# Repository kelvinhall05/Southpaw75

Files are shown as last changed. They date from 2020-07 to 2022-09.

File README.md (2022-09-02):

# Southpaw75

The Southpaw75 is a budget FR4 keyboard designed to make a southpaw-style layout available to everyone with as few compromises as possible.

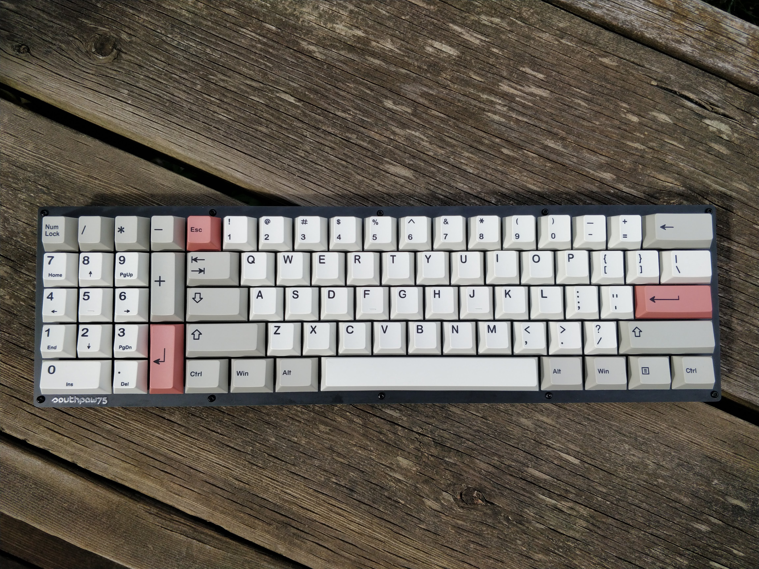
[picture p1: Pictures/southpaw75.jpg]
Image of Southpaw


### Disclaimer: You must follow this guide in the order it is written. Assembling stuff in the wrong order (specifically your Pro Micro or Elite C and its headers) will likely result in you having to desolder components and significantly increase the amount of time it takes to assemble. I am not responsible for boards damaged during assembly. I highly recommend you read through the entire guide before starting assembly.

### Please also note that the pictures in this guide were mostly taken after I had already assembled a prototype, and I did not have enough diodes or any switches to fully assemble another board. Please only use the pictures in this guide as a reference for the step they follow and not as the guide itself.

# Assembly:
### This is what the back of an empty PCB looks like (please note, the GB version has some minor changes):
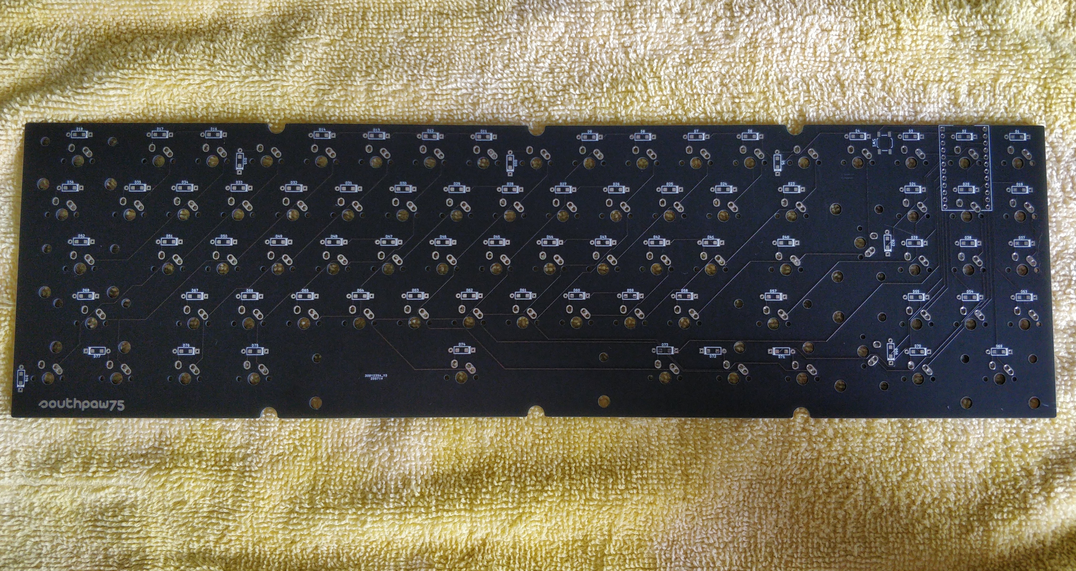
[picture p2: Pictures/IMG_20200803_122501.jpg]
Image of empty PCB

### 1. Bend the legs of all your diodes so they look like this:
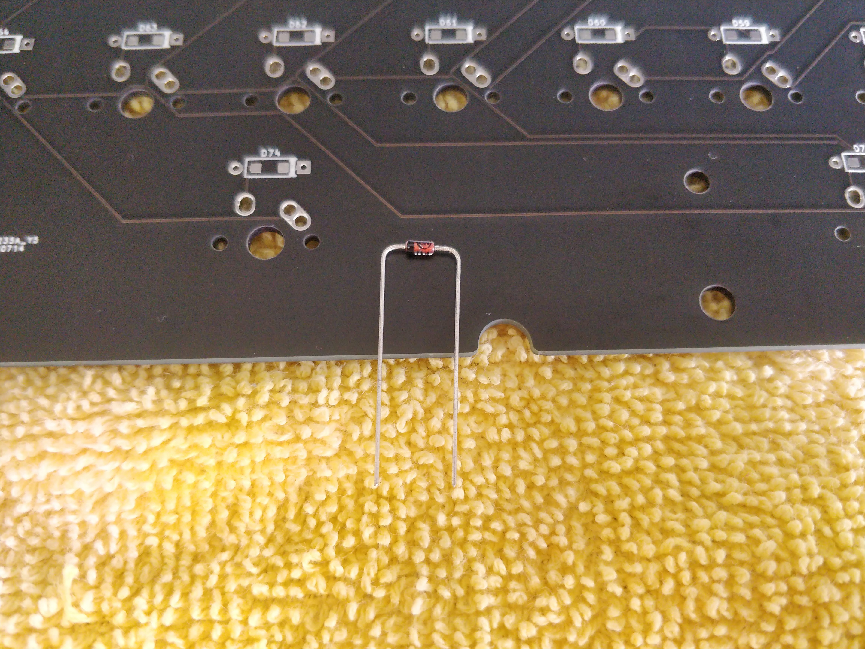
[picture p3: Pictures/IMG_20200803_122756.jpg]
Image of diode legs

### 2. Put the diodes through the PCB so the legs stick out the front side of the board and so the diode is flush with the back, making sure the black line on the diode faces the square pad:
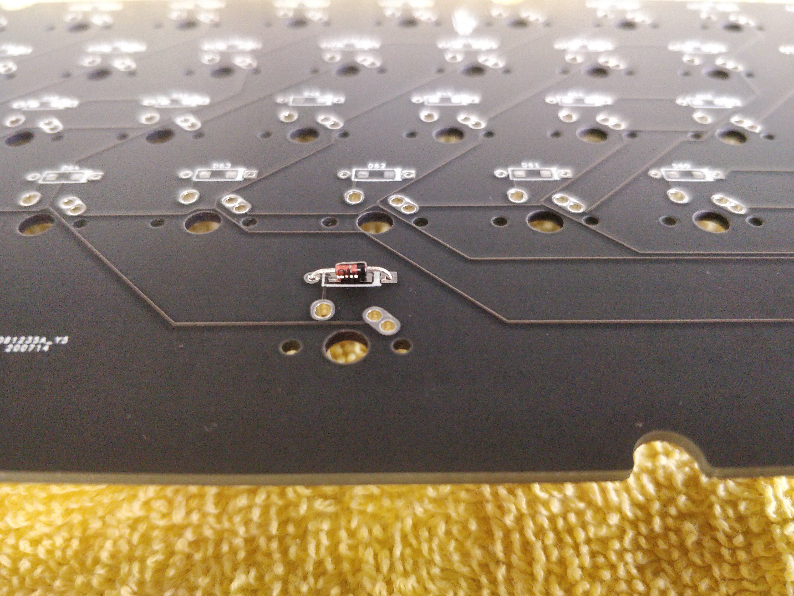
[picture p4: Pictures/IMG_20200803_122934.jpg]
Image of diode in PCB

### 3. Solder from the back and snip the legs:
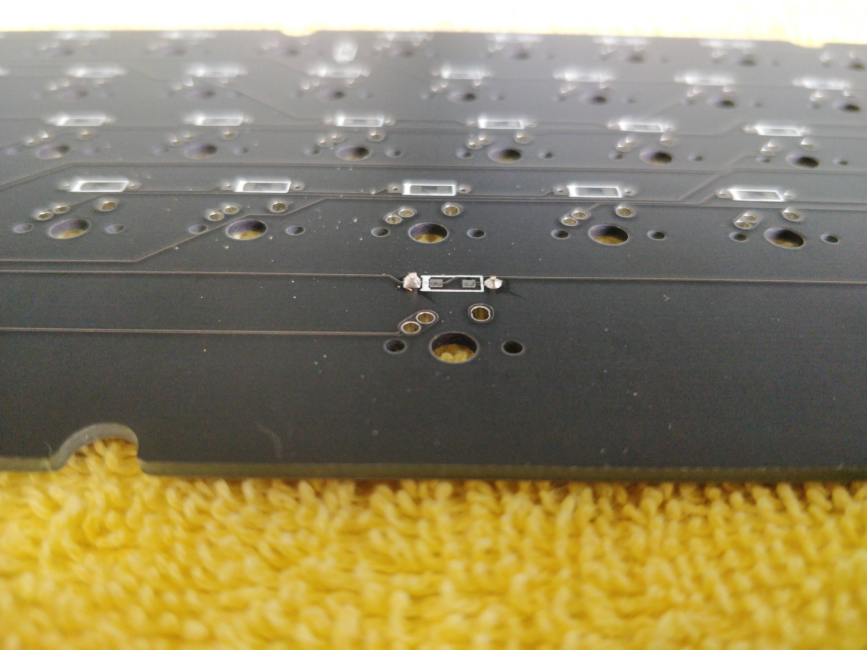
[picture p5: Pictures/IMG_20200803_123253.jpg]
Image of soldered diode

### 4. Repeat for all diodes (you will have to solder 78, and you may have several extras). Please note that several diodes have their footprint rotated but are electrically identical, meaning black stripe will still go to square pad.
### 5. Solder your reset button to the PCB (use tweezers to hold it down, as the metal will conduct heat from your iron and burn your finger)
### Note: If you've lost your reset button, don't worry. Shorting the two pads closest to the edge of the PCB or the two closest to the inside will reset your controller. After all, that's all the button does :)
### 6. Place your Pro Micro or Elite C onto its pin headers and sit it into the board so the Pro Micro is on the back of the PCB (the side with the Southpaw logo) and tape it down to temporarily hold it in place. This helps align the pin headers properly. It doesn't matter whether you put the shorter pins on the PCB or the longer ones; either way, you will have to snip the longer ones once you've soldered them in. **DO NOT SOLDER THE PRO MICRO OR ELITE C TO THE PIN HEADERS YET!**
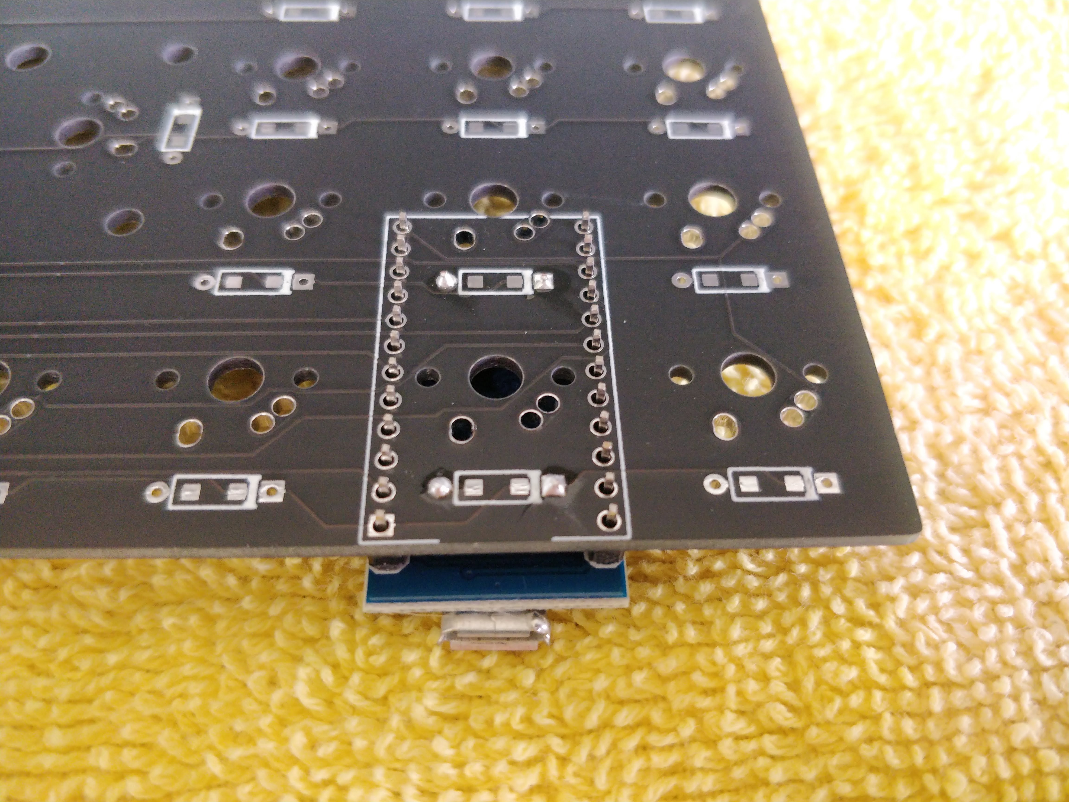
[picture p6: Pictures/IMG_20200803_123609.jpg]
Image of seated Pro Micro

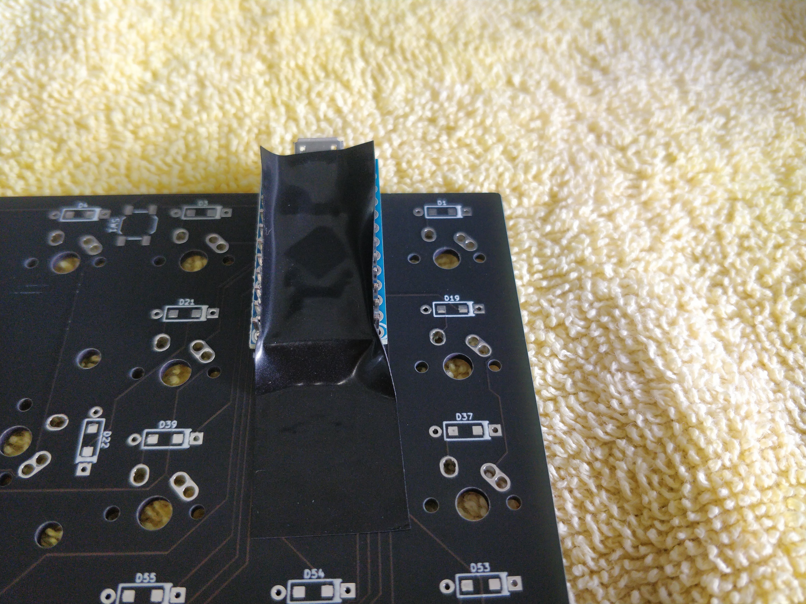
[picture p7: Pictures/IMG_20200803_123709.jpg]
Image of taped Pro Micro

### 7. Solder in the pin headers from the front side of the PCB. **Do not solder the Pro Micro or Elite C yet, just the headers!**
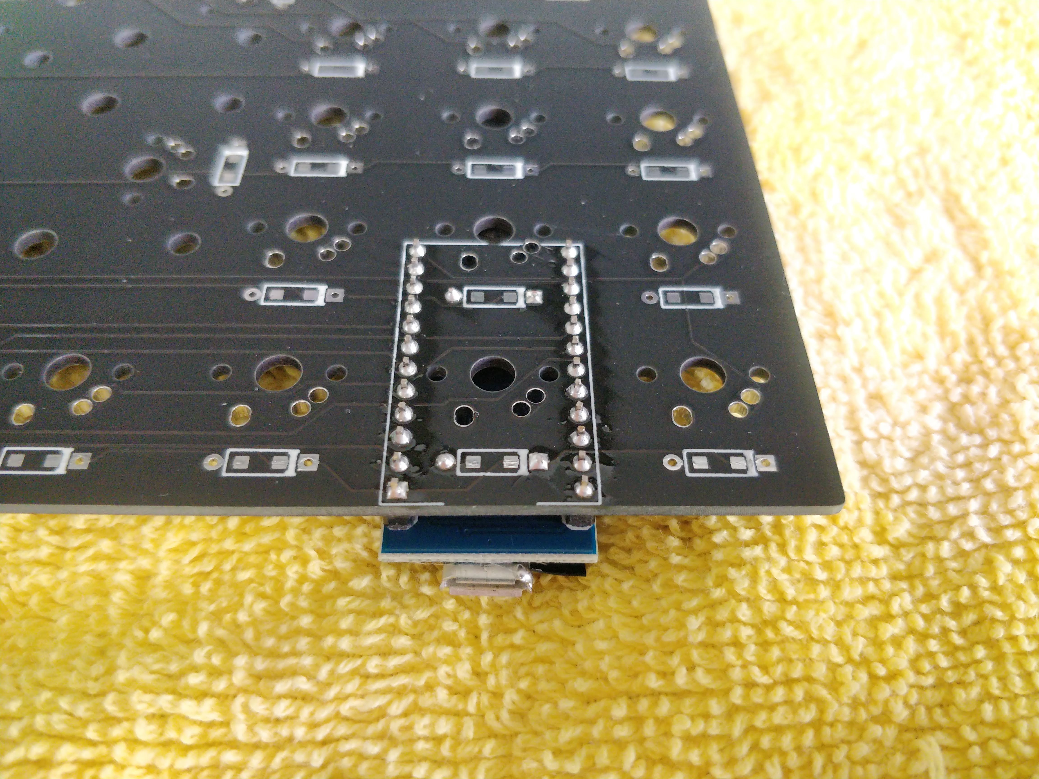
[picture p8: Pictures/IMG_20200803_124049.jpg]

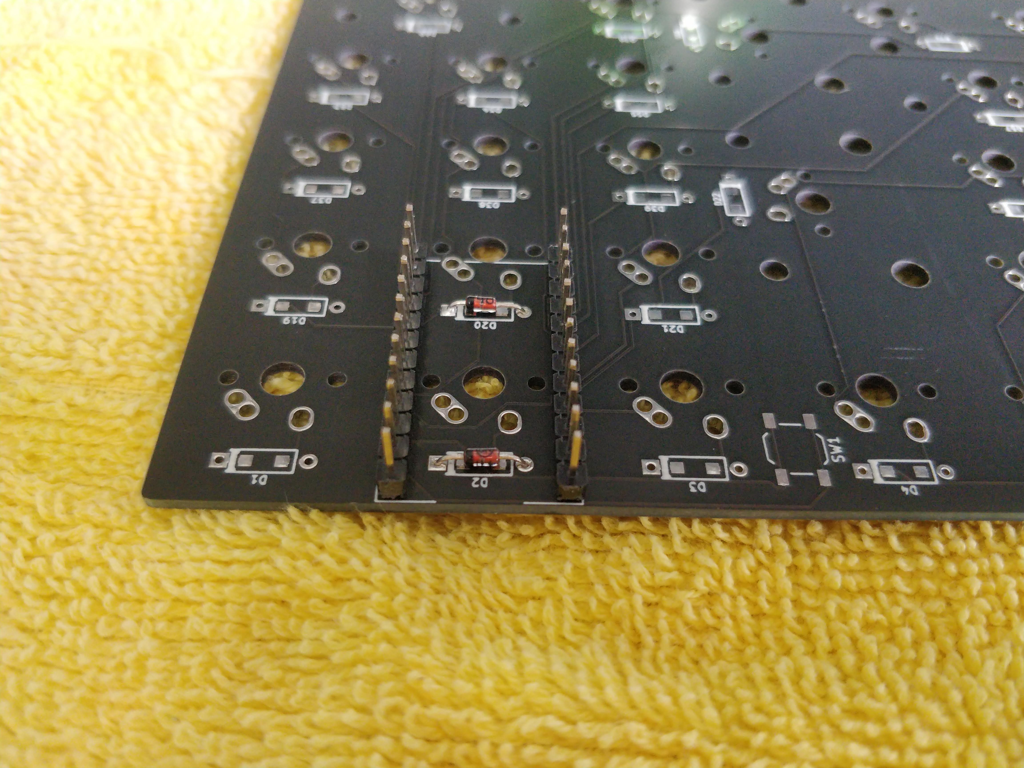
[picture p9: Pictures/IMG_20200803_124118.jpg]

### 8. Attach your stabs to the PCB (some PCB stabs might be a tight fit with the plate; do not be afraid to push, you won't break it)
### 9. Mount switches in the corner of the plate to align it, then lower the plate onto the PCB
### 10. Add the rest of your switches and solder them all in
### 11. Once you have verified that all your diodes, switches, and Pro Micro or Elite C pin headers are soldered properly, you can now solder your Pro Micro or Elite C onto the pin headers:
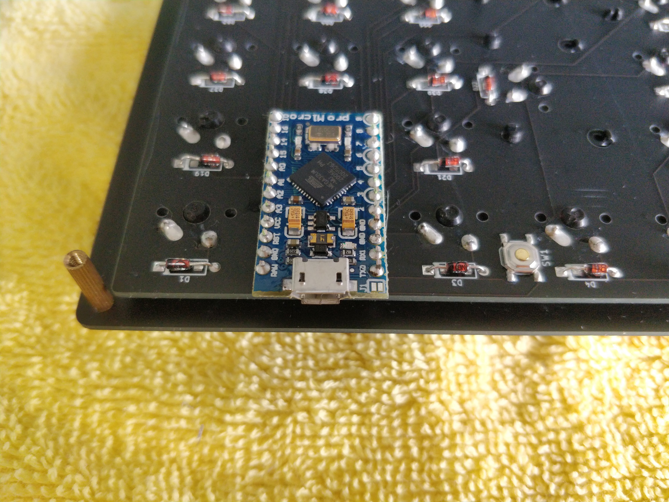
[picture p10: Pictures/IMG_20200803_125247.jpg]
Image of soldered Pro Micro

### Here is what a completed PCB will look like:
Image of completed PCB
### 12. Attach standoffs to the bottom of the plate using screws from the other side
### 13. Screw on the bottom plate
# Flashing instructions for Linux:
### 1. Plug your Pro Micro or Elite C in
### 2. Open up the [QMK configurator](https://config.qmk.fm/#/southpaw75/LAYOUT) and create your desired layout
### 3. Download the .json file (on the left, next to keymap.json)
### 4. Open up a command line
### 5. Type ```qmk flash /path/to/layout.json``` (obviously replacing the file path with the path to your downloaded layout) and follow any additional instructions
### One thing to note is that you can compile a .hex file on the configurator and flash that with avrdude, however, I prefer the method outlined above.
# Flashing instructions for Windows:
### Please keep in mind that I do not run Windows on my own system and cannot 100% verify this flashing procedure will work or if it requires any other configuration. I highly recommend you check the QMK docs if something is not working. I am unable to help with any flashing problems if you run Windows.
### 1. Plug your Pro Micro or Elite C in
### 2. Open up the [QMK configurator](https://config.qmk.fm/#/southpaw75/LAYOUT) and create your desired layout
### 3. Click "compile" in the upper right, and once it's done, download the .hex by clicking "firmware"
### 4. Open up QMK toolbox and load your downloaded .hex
### 5. Click "flash" and follow any additional instructions

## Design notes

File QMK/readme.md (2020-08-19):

# Southpaw75

Southpaw75

60% with southpaw numpad.

* Keyboard Maintainer: [kelvinhall05](https://github.com/kelvinhall05/)
* Hardware Supported: Southpaw75 Pro Micro PCB
* Hardware Availability: https://github.com/kelvinhall05/southpaw75

Make example for this keyboard (after setting up your build environment):

    make southpaw75:default

See the [build environment setup](https://docs.qmk.fm/#/getting_started_build_tools) and the [make instructions](https://docs.qmk.fm/#/getting_started_make_guide) for more information. Brand new to QMK? Start with our [Complete Newbs Guide](https://docs.qmk.fm/#/newbs).

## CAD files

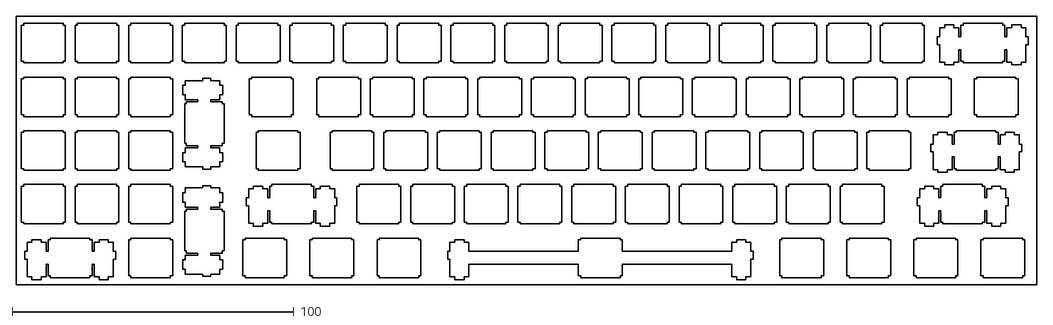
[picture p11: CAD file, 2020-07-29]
Plate/plate.dxf
361.9 x 95.2

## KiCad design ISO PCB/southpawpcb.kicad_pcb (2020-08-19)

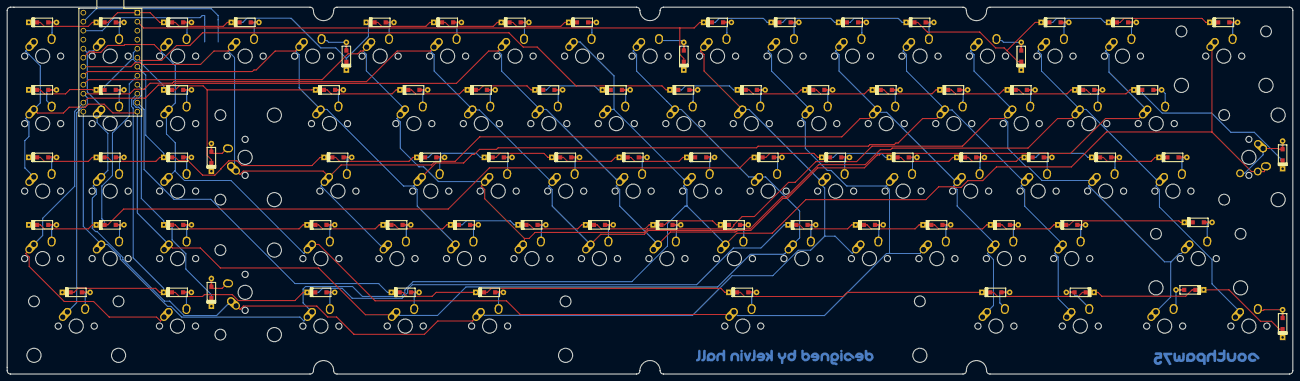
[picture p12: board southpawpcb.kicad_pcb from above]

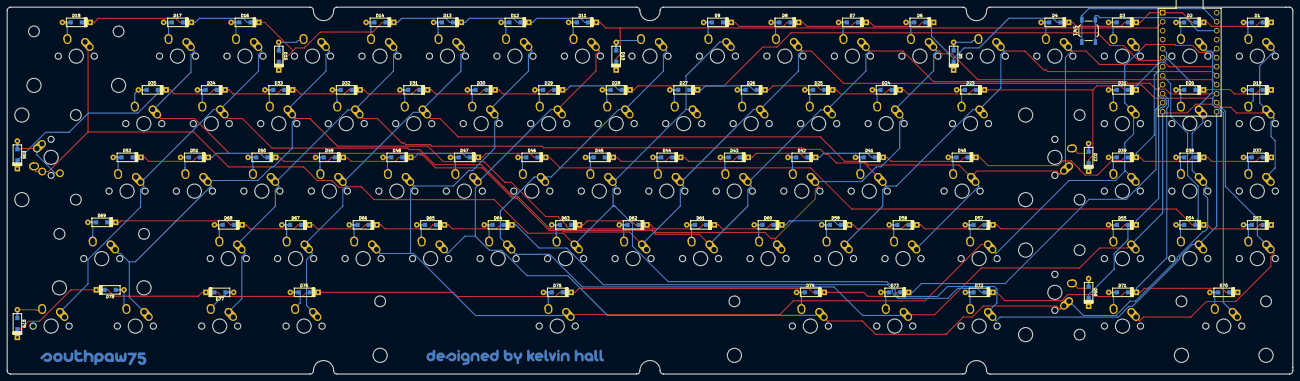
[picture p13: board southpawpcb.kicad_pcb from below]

Board: 2 copper layers, 362.9 x 103.6 mm, 164 parts (85 on the bottom side), 99 nets.

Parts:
D1, D2, D3, D4, D5, D6, D7, D8, D9, D10, D11, D12, D13, D14, D15, D16, D17, D18, D19, D20, D21, D22, D23, D24, D25, D26, D27, D28, D29, D30, D31, D32, D33, D34, D35, D36, D37, D38, D39, D40, D41, D42, D43, D44, D45, D46, D47, D48, D49, D50, D51, D52, D53, D54, D55, D56, D57, D58, D59, D60, D61, D62, D63, D64, D65, D66, D67, D68, D69, D70, D71, D72, D73, D74, D75, D76, D77, D78, D79: D; D_SOD123_axial-dual
G1: LOGO; designedbykelvinhallcopy
G2: LOGO; designedbykelvinhall
G3: LOGO; southpaw75smallcopy
G4: LOGO; southpaw75small
K1, K2, K3, K4, K5, K6, K7, K8, K9, K10, K11, K12, K13, K14, K15, K16, K17, K19, K20, K21, K24, K25, K26, K27, K28, K29, K30, K31, K32, K33, K34, K35, K37, K38, K39, K41, K42, K43, K44, K45, K46, K47, K48, K49, K50, K51, K52, K53, K54, K55, K58, K59, K60, K61, K62, K63, K64, K65, K66, K67, K68, K71: KEYSW; MX-1U-NoLED
K18, K22, K56, K70: KEYSW; MX-2U-NoLED
K23: KEYSW; MX-1.5U-NoLED
K36: KEYSW; MX-ISO
K40: KEYSW; MX-1.75U-NoLED
K57, K72, K73, K74, K76, K77, K78, K79: KEYSW; MX-1.25U-NoLED
K69: KEYSW; MX-2.75U-NoLED
K75: KEYSW; MX-6.25U-NoLED
SW1: Reset; SW_SPST_TL3342
U1: ProMicro

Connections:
unnamed: D1.1, D2.1, D3.1, D4.1, D5.1, D6.1, D7.1, D8.1, D9.1, U1.1
unnamed: D1.2, K1.2
unnamed: D2.2, K2.2
unnamed: D3.2, K3.2
unnamed: D4.2, K4.2
unnamed: D5.2, K5.2
unnamed: D6.2, K6.2
unnamed: D7.2, K7.2
unnamed: D8.2, K8.2
unnamed: D9.2, K9.2
unnamed: D10.1, D11.1, D12.1, D13.1, D14.1, D15.1, D16.1, D17.1, D18.1, U1.2
unnamed: D10.2, K10.2
unnamed: D11.2, K11.2
unnamed: D12.2, K12.2
unnamed: D13.2, K13.2
unnamed: D14.2, K14.2
unnamed: D15.2, K15.2
unnamed: D16.2, K16.2
unnamed: D17.2, K17.2
unnamed: D18.2, K18.2
unnamed: D19.1, D20.1, D21.1, D22.1, D23.1, D24.1, D25.1, D26.1, D27.1, U1.5
unnamed: D19.2, K19.2
unnamed: D20.2, K20.2
unnamed: D21.2, K21.2
unnamed: D22.2, K22.2
unnamed: D23.2, K23.2
unnamed: D24.2, K24.2
unnamed: D25.2, K25.2
unnamed: D26.2, K26.2
unnamed: D27.2, K27.2
unnamed: D28.1, D29.1, D30.1, D31.1, D32.1, D33.1, D34.1, D35.1, D36.1, U1.6
unnamed: D28.2, K28.2
unnamed: D29.2, K29.2
unnamed: D30.2, K30.2
unnamed: D31.2, K31.2
unnamed: D32.2, K32.2
unnamed: D33.2, K33.2
unnamed: D34.2, K34.2
unnamed: D35.2, K35.2
unnamed: D36.2, K36.2
unnamed: D37.1, D38.1, D39.1, D40.1, D41.1, D42.1, D43.1, D44.1, D45.1, U1.7
unnamed: D37.2, K37.2
unnamed: D38.2, K38.2
unnamed: D39.2, K39.2
unnamed: D40.2, K40.2
unnamed: D41.2, K41.2
unnamed: D42.2, K42.2
unnamed: D43.2, K43.2
unnamed: D44.2, K44.2
unnamed: D45.2, K45.2
unnamed: D46.1, D47.1, D48.1, D49.1, D50.1, D51.1, D52.1, D53.1, D54.1, U1.8
unnamed: D46.2, K46.2
unnamed: D47.2, K47.2
unnamed: D48.2, K48.2
unnamed: D49.2, K49.2
unnamed: D50.2, K50.2
unnamed: D51.2, K51.2
unnamed: D52.2, K52.2
unnamed: D53.2, K53.2
unnamed: D54.2, K54.2
unnamed: D55.1, D56.1, D57.1, D58.1, D59.1, D60.1, D61.1, D62.1, D63.1, U1.9
unnamed: D55.2, K55.2
unnamed: D56.2, K56.2
unnamed: D57.2, K57.2
unnamed: D58.2, K58.2
unnamed: D59.2, K59.2
unnamed: D60.2, K60.2
unnamed: D61.2, K61.2
unnamed: D62.2, K62.2
unnamed: D63.2, K63.2
unnamed: D64.1, D65.1, D66.1, D67.1, D68.1, D69.1, D70.1, D71.1, D72.1, U1.10
unnamed: D64.2, K64.2
unnamed: D65.2, K65.2
unnamed: D66.2, K66.2
unnamed: D67.2, K67.2
unnamed: D68.2, K68.2
unnamed: D69.2, K69.2
unnamed: D70.2, K70.2
unnamed: D71.2, K71.2
unnamed: D72.2, K72.2
unnamed: D73.1, D74.1, D75.1, D76.1, D77.1, D78.1, D79.1, U1.11
unnamed: D73.2, K73.2
unnamed: D74.2, K74.2
unnamed: D75.2, K75.2
unnamed: D76.2, K76.2
unnamed: D77.2, K77.2
unnamed: D78.2, K78.2
unnamed: D79.2, K79.2
unnamed: K1.1, K10.1, K19.1, K28.1, K37.1, K46.1, K55.1, K64.1, K73.1, U1.12
unnamed: K2.1, K11.1, K20.1, K29.1, K38.1, K47.1, K56.1, K65.1, K74.1, U1.20
unnamed: K3.1, K12.1, K21.1, K30.1, K39.1, K48.1, K57.1, K66.1, K75.1, U1.19
unnamed: K4.1, K13.1, K22.1, K31.1, K40.1, K49.1, K58.1, K67.1, K76.1, U1.18
unnamed: K5.1, K14.1, K23.1, K32.1, K41.1, K50.1, K59.1, K68.1, K77.1, U1.17
unnamed: K6.1, K15.1, K24.1, K33.1, K42.1, K51.1, K60.1, K69.1, K78.1, U1.16
unnamed: K7.1, K16.1, K25.1, K34.1, K43.1, K52.1, K61.1, K70.1, K79.1, U1.15
unnamed: K8.1, K17.1, K26.1, K35.1, K44.1, K53.1, K62.1, K71.1, U1.14
unnamed: K9.1, K18.1, K27.1, K36.1, K45.1, K54.1, K63.1, K72.1, U1.13
unnamed: SW1.1, U1.23
unnamed: SW1.2, U1.22

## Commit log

2020-07-29 Adding Southpaw75 files
    [plate.dxf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]
2020-08-19 updating QMK and PCBs
    [southpawcase-B_Cu.gbl, southpawcase-B_Mask.gbs, southpawcase-B_Paste.gbp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]
2020-09-03 Update assembly guide
2021-09-15 Fixing missing libraries, redrawing schematic
    [southpawpcb.dsn, southpawpcb.sch]
